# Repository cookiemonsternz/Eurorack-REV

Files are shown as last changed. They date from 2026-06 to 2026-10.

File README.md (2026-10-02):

# REV
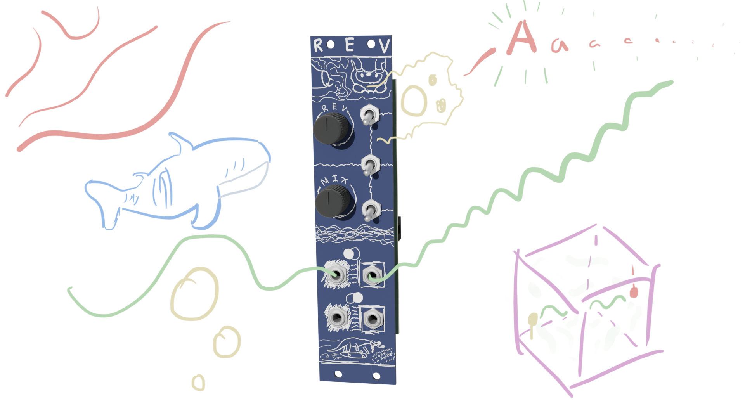
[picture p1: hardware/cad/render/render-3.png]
Render 3

_Digital reverb / delay eurorack module, user programmable and customisable._

#### What?
The next effect in a series of eurorack modules! REV is a custom digital reverb/delay processer, utilising the rp2040 mcu. Includes firmware for a basic algorithmic reverb, completely configurable via software. Default configuration uses 60kb of sram out of 264kb max. 

In terms of controls, REV features two potentiometers and 3 switches, which are by default configured to control reverb length and mix, with the switches adjusting brightness, density and stereo mixing.

#### Why?
Reverb is a very widely used effect, and arguably one of the most important in synthesizers. It sounds pretty cool but is unfortunately quite tricky to do completely analog. This module aims to provide a convenient and open source base to not only use as a reverb module, but also to prototype other digital effects.

I personally decided to make it due to my frustration with constantly having to lug around my laptop whenever I wanted reverb on my synth (which doesn't have an in-built fx section). A eurorack module is much more convenient. Having it be my own hardware allows for much more customisation than off the shelf modules / pedals, which I find very attractive.

#### How to use?
REV is a stereo board, it has an input and output for left and right, and the controls are all labelled.

In terms of getting it set up, you'll need to program the rp2040. To do this, bridge J4, which will allow you to program the flash, and then plug in the usb port. The rp2040 should show up as USB Mass Storage Device. Copy the uf2 file from the releases tab folder into the device and then disconnect J4 and unplug the usb. When you power it up via the eurorack power connector (not usb) the module should be functional.

## Renders
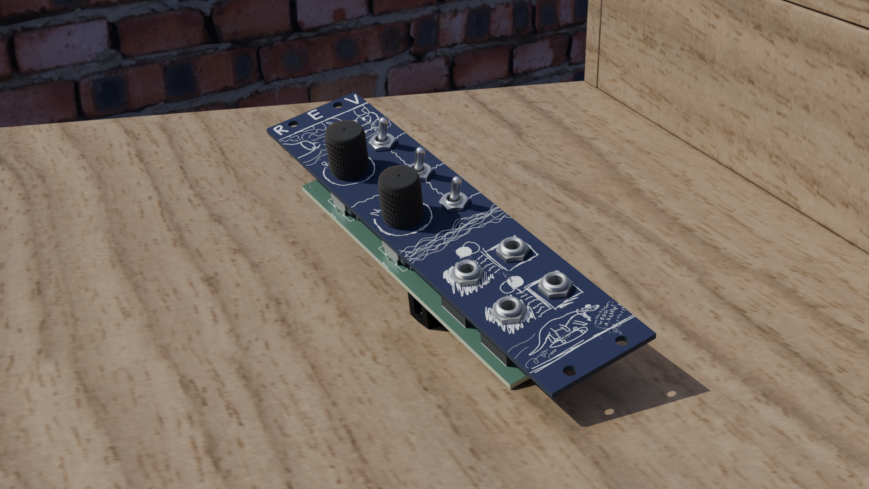
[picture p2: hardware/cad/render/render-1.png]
Render 1

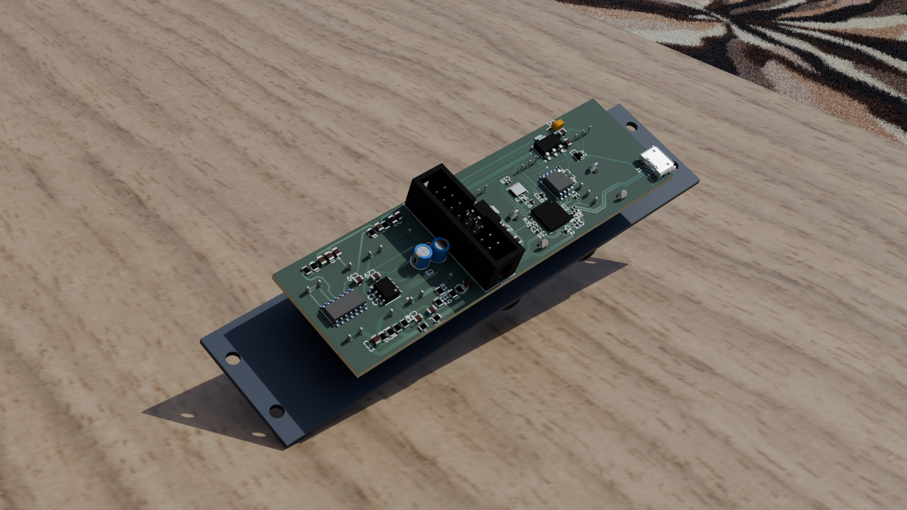
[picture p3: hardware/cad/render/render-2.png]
Render 2

Board front
Board back
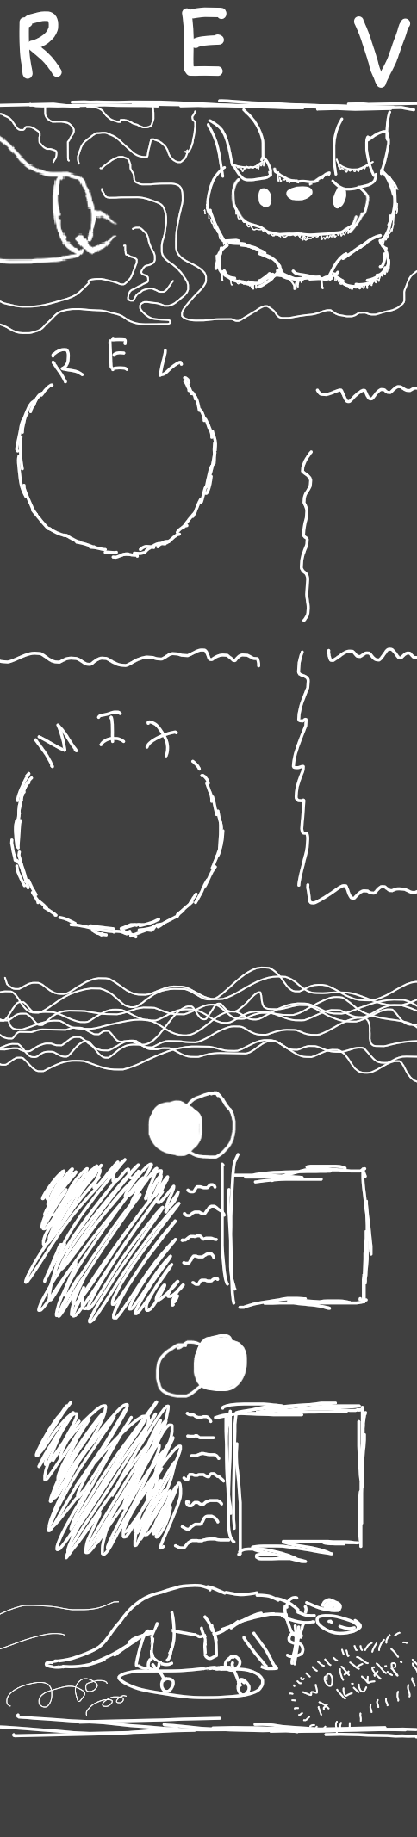
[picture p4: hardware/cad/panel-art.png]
Panel art


## Schematics
Schematic
PCB Front
PCB Back

## Zine Page
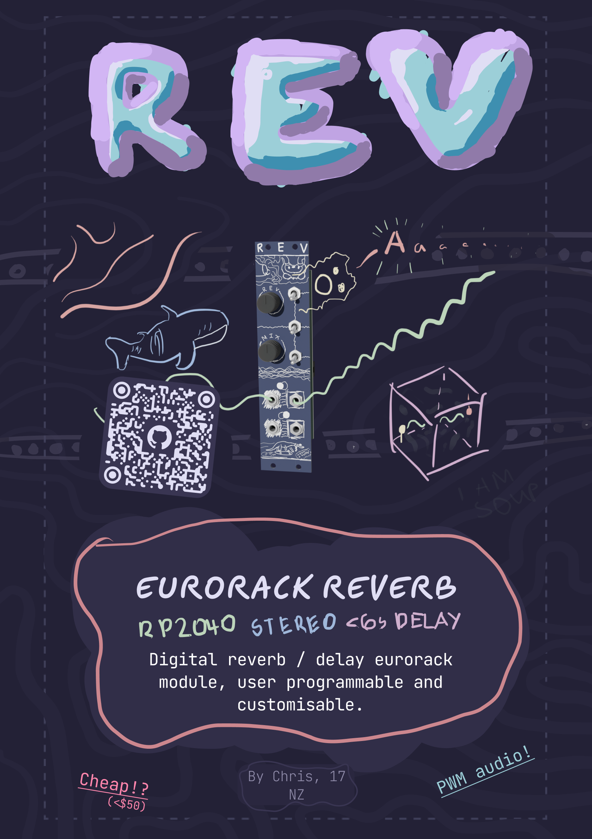
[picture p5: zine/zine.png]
Zine page


## BOM
_Needed is how many I personally need :)_
| Part | Quantity | Needed | Source | Link | Lot / Min Amount | Unit | Net | Running |
|---|---|---|---|---|---|---|---|---|
| **Capacitors** | | | | | | | | |
| 100n Cap, 0805 | 19 | 19 | JLCPCB | https://jlcpcb.com/partdetail/YAGEO-CC0805KRX7R9BB104/C49678 | 1 | $0.0094 | $0.1786 | $0.18 |
| 1u Cap, 0805 | 2 | 2 | JLCPCB | https://jlcpcb.com/partdetail/29074-CL21B105KBFNNNE/C28323 | 1 | $0.0190 | $0.0380 | $0.22 |
| 10u Cap, 0805 | 4 | 4 | JLCPCB | https://jlcpcb.com/partdetail/16532-CL21A106KAYNNNE/C15850 | 1 | $0.0472 | $0.1888 | $0.41 |
| 47u Cap, 0805 | 2 | 2 | JLCPCB | https://jlcpcb.com/partdetail/17464-CL21A476MQYNNNE/C16780 | 1 | $0.0921 | $0.1842 | $0.59 |
| 10u Electrolytic Cap, D4.0xP1.5 | 2 | 0 | LCSC | https://www.lcsc.com/product-detail/C88726.html | 10 | $0.0564 | $0.5600 | $1.15 |
| 22u Tantalum Cap, CASE-A-3216-18(mm) | 2 | 2 | LCSC | https://www.lcsc.com/product-detail/C11366.html | 1 | $0.2379 | $0.4758 | $1.63 |
| **Resistors** | | | | | | | | |
| 22? Resistor, 0805 | 2 | 2 | JLCPCB | https://jlcpcb.com/partdetail/18249-0805W8F220JT5E/C17561 | 1 | $0.0027 | $0.0054 | $1.63 |
| 100? Resistor, 0805 | 2 | 2 | JLCPCB | https://jlcpcb.com/partdetail/18096-0805W8F1000T5E/C17408 | 1 | $0.0023 | $0.0046 | $1.64 |
| 220? Resistor, 0805 | 2 | 2 | JLCPCB | https://jlcpcb.com/partdetail/18245-0805W8F2200T5E/C17557 | 1 | $0.0031 | $0.0062 | $1.64 |
| 3.9k? Resistor, 0805 | 2 | 2 | JLCPCB | https://jlcpcb.com/partdetail/18302-0805W8F3901T5E/C17614 | 1 | $0.0031 | $0.0062 | $1.65 |
| 10k? Resistor, 0805 | 5 | 5 | JLCPCB | https://jlcpcb.com/partdetail/18102-0805W8F1002T5E/C17414 | 1 | $0.0029 | $0.0145 | $1.66 |
| 1M? Resistor, 0805 | 2 | 2 | JLCPCB | https://jlcpcb.com/partdetail/18202-0805W8F1004T5E/C17514 | 1 | $0.0024 | $0.0048 | $1.67 |
| **Other** | | | | | | | | |
| Schottky Diode, SOD-323 | 2 | 2 | JLCPCB | https://jlcpcb.com/partdetail/GuangdongHottech-1N5819WS/C191023 | 1 | $0.0111 | $0.0222 | $1.69 |
| PJ301M-12 Jacks | 4 | 0 | Aliexpress | www.aliexpress.com/item/1005004864182675.html | 10 | $4.4000 | $0.0000 | $1.69 |
| RK09K 100k Potentiometer | 2 | 0 | Aliexpress | https://www.aliexpress.com/item/1005007278123055.html | 5 | $1.0400 | $0.0000 | $1.69 |
| TL072CDT | 1 | 1 | JLCPCB | https://jlcpcb.com/partdetail/STMicroelectronics-TL072CDT/C6961 | 1 | $0.1568 | $0.1568 | $1.85 |
| X322512MSB4SI 12MHz Crystal | 1 | 1 | JLCPCB | https://jlcpcb.com/partdetail/YXC_CrystalOscillators-X322512MSB4SI/C9002  | 1 | $0.0740 | $0.0740 | $1.92 |
| 74HC04D Logic Inverter | 1 | 1 | JLCPCB | https://jlcpcb.com/partdetail/Nexperia-74HC04D653/C5590 | 1 | $0.1521 | $0.1521 | $2.07 |
| W25Q128JVS Flash | 1 | 1 | JLCPCB | https://jlcpcb.com/partdetail/WinbondElec-W25Q128JVSIQ/C97521 | 1 | $2.6146 | $2.6146 | $4.69 |
| AMS1117-3.3 LDO | 2 | 2 | JLCPCB | https://jlcpcb.com/partdetail/Advanced_MonolithicSystems-AMS1117_33/C6186 | 1 | $0.2024 | $0.4048 | $5.09 |
| RP2040 MCU | 1 | 1 | JLCPCB | https://jlcpcb.com/partdetail/RaspberryPi-RP2040/C2040 | 1 | $0.9843 | $0.9843 | $6.08 |
| IDC Connector | 1 | 0 | LCSC | https://www.lcsc.com/product-detail/C7430313.html | 5 | $0.0834 | $0.0000 | $6.08 |
| USB B Micro Port | 1 | 1 | JLCPCB | https://jlcpcb.com/partdetail/SHOUHAN-MicroXNJ/C404969 | 1 | $0.0406 | $0.0406 | $6.12 |
| SPDT Switch | 3 | 0 | Aliexpress | https://www.aliexpress.com/item/1005005370002265.html | 5 | $0.8520 | $0.0000 | $6.12 |
| **Non-Components** | | | | | | | | |
| Aluminium Plate (100x200x2mm) | 1 | 1 | Aliexpress | https://www.aliexpress.com/item/1005007160296738.html | 1 | $6.2300 | $6.2300 | $12.35  |
| PCB | 1 | 1 | JLCPCB | NA | 5 | $0.8200 | $4.1000 | $16.45  |
| **Total** | | | | | | | | $16.45  |

| Totals | Money  |
|---|---|
| Aliexpress, Inc. Shipping + Tax | $7.35  |
| JLCPCB, Inc. Shipping + Tax | $41.21 |
| **Total** | $48.56 |

## CAD Links
Heres the links to the CAD source, Onshape:
[Panel source](https://cad.onshape.com/documents/1214f87d69295045284472ae/w/920e2a43c1f3f44d8378acda/e/9f1143cafdcad0010397ac9a)

## Directory Structure
- **hardware/**
    - **bom/** - BOM Files (CSV and LibreOffice Calc)
    - **cad/** - CAD Files
        - **render/** - Files for rendering (inc. gltf models)
    - **rev/** - KiCad files
        - **lib/** - External libraries
        - **production/** - Production files (Gerber, etc.)
        - **plots/** - Schematic plot
- **journals/**
- **zine/** - Zine page

## References
[RP2040 Hardware Guide](https://pip-assets.raspberrypi.com/categories/814-rp2040/documents/RP-008279-DS-1-hardware-design-with-rp2040.pdf)

#### This project was created for [Hack Club](https://hackclub.com/) - [Fallout](https://fallout.hackclub.com/)

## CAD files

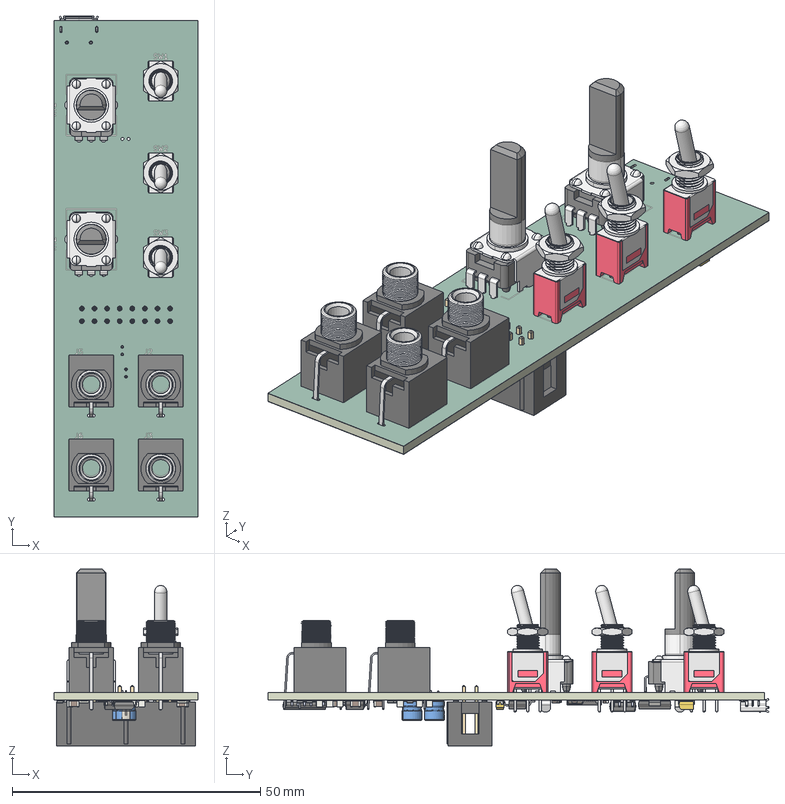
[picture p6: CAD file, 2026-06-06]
hardware/cad/board.step
29.0 x 101.0 x 35.6 mm
200-MSP-1-T3-B1-M2-PE-rev2 x 3
RK09K1130BGM x 2
D_SOD-323 x 2
C_0805_2012Metric x 16
R_0805_2012Metric x 14
C_0402_1005Metric x 13
CP_EIA-3216-18_Kemet-A x 2
IDC-Header_2x08_P2.54mm_Vertical
R_0402_1005Metric x 4
CP_Radial_D4.0mm_P1.50mm x 2
Crystal_SMD_3225-4Pin_3.2x2.5mm
SOT-223 x 2
QFN-56-1EP_7x7mm_P0.4mm_EP3.2x3.2mm
MICROXNJ
W25Q128JVSIQ
74HC04D
SOIC-8_3.9x4.9mm_P1.27mm
rev_silkscreen x 2
rev_soldermask x 2
rev_PCB

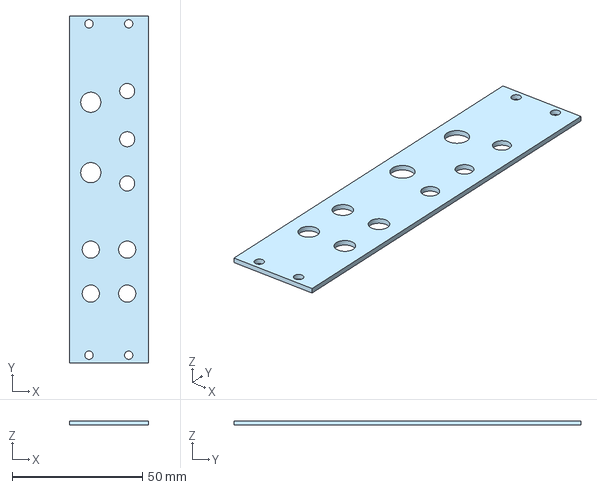
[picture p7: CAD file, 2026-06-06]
hardware/cad/Panel.step
30.2 x 133.3 x 1.59 mm

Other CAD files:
hardware/cad/render/render.blend

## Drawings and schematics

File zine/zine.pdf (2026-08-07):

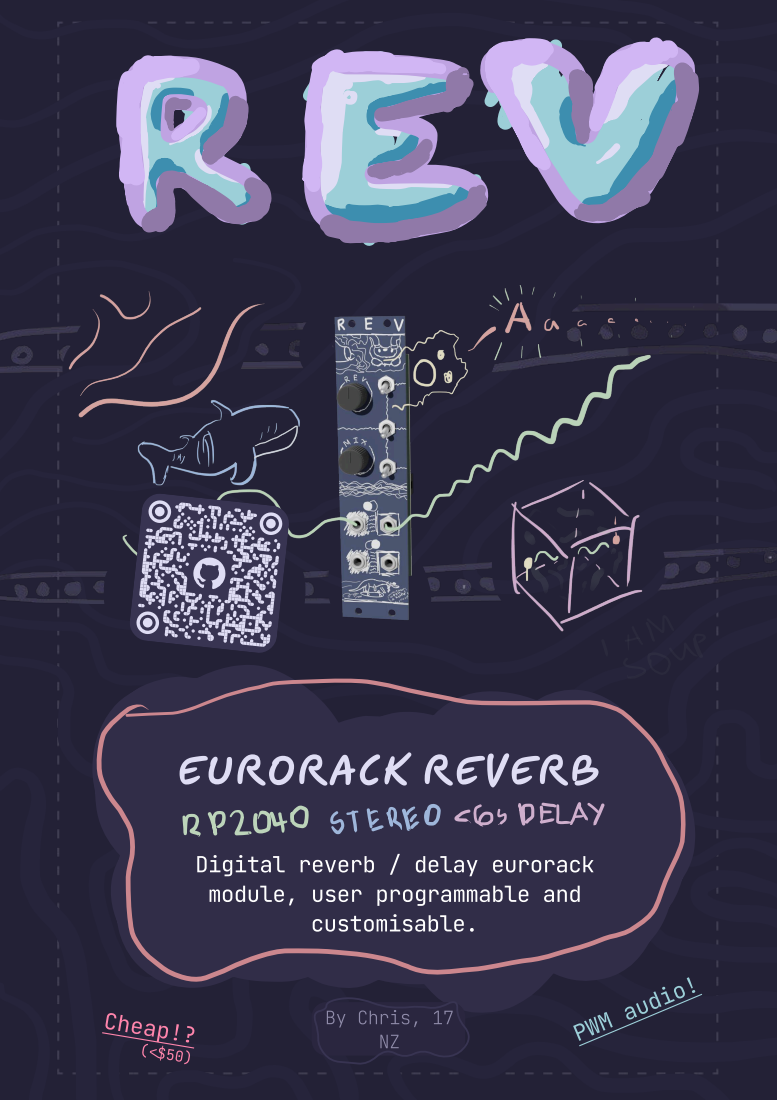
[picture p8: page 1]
EURORACK REVERB; customisable.; PWM audio!; By Chris, 17 NZ; Cheap!?

Digital reverb / delay eurorack
module, user programmable and

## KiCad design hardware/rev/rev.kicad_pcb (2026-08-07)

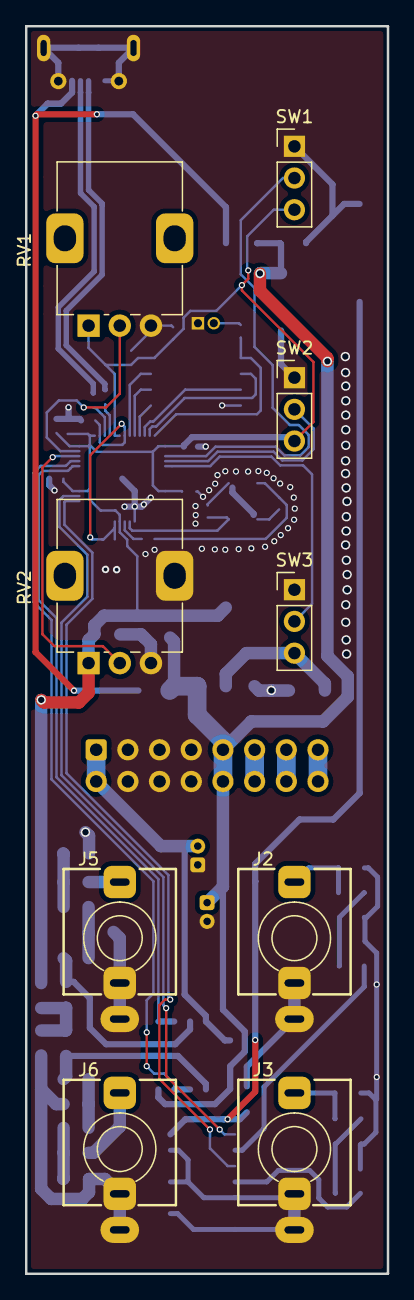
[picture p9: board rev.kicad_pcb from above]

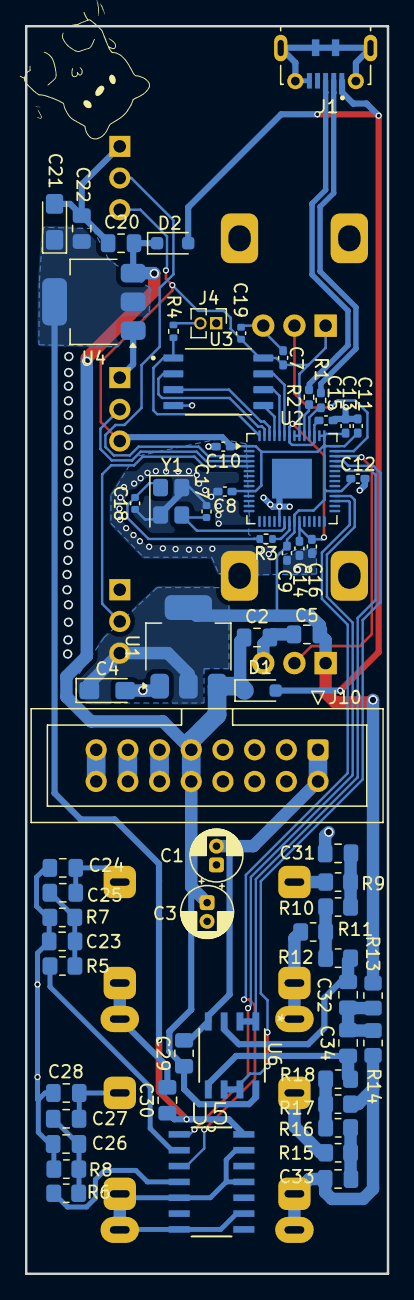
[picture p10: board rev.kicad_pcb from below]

Board: 2 copper layers, 29.0 x 100.0 mm, 72 parts (63 on the bottom side), 45 nets.

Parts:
C1, C3: 10u; CP_Radial_D4.0mm_P1.50mm
C2, C5, C20, C22: 10u; C_0805_2012Metric_Pad1.18x1.45mm_HandSolder
C4, C21: 22u; CP_EIA-3216-18_Kemet-A_HandSolder
C7, C8, C9, C10, C11, C12, C14, C15: 100n; C_0402_1005Metric_Pad0.74x0.62mm_HandSolder
C13, C16: 1u; C_0402_1005Metric_Pad0.74x0.62mm_HandSolder
C17, C18: 20p; C_0402_1005Metric
C19: 100n; C_0402_1005Metric
C23, C24, C26, C28, C29, C30, C31, C32, C33, C34: 100n; C_0805_2012Metric_Pad1.18x1.45mm_HandSolder
C25, C27: 47u; C_0805_2012Metric_Pad1.18x1.45mm_HandSolder
D1, D2: D_Schottky; D_SOD-323_HandSoldering
J1: USB_B_Micro; SHOUHAN_MICROXNJ
J2: OUT_L; Jack_3.5mm_QingPu_WQP-PJ301M-12_Vertical
J3: OUT_R; Jack_3.5mm_QingPu_WQP-PJ301M-12_Vertical
J4: Conn_01x02; PinHeader_1x02_P1.27mm_Vertical
J5: IN_L; Jack_3.5mm_QingPu_WQP-PJ301M-12_Vertical
J6: IN_R; Jack_3.5mm_QingPu_WQP-PJ301M-12_Vertical
J10: Conn_02x08_Odd_Even; IDC-Header_2x08_P2.54mm_Vertical
R1, R2: 22; R_0402_1005Metric_Pad0.72x0.64mm_HandSolder
R3, R4: 1k; R_0402_1005Metric
R5, R6: 220; R_0805_2012Metric_Pad1.20x1.40mm_HandSolder
R7, R8: 100; R_0805_2012Metric_Pad1.20x1.40mm_HandSolder
R9, R12, R15, R18: 1M; R_0805_2012Metric_Pad1.20x1.40mm_HandSolder
R10, R13, R14, R16: 10k; R_0805_2012Metric_Pad1.20x1.40mm_HandSolder
R11, R17: 3.9k; R_0805_2012Metric_Pad1.20x1.40mm_HandSolder
RV1, RV2: 100k; Potentiometer_Alps_RK09K_Single_Vertical
SW1, SW2, SW3: SW_SPDT; PinHeader_1x03_P2.54mm_Vertical
U1, U4: AMS1117-3.3; SOT-223-3_TabPin2
U2: RP2040; QFN-56-1EP_7x7mm_P0.4mm_EP3.2x3.2mm
U3: W25Q128JVS; SOIC127P790X216-8N
U5: 74HC04; SOIC127P600X175-14N
U6: TL072; D8_TEX_STM
Y1: YSX321SL 12MHz Crystal; Crystal_SMD_3225-4Pin_3.2x2.5mm

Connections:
+3.3V: C4.1, C5.1, C7.1, C8.1, C9.1, C10.1, C11.1, C12.1, C13.2, C19.1, R13.1, RV1.1, RV2.1, SW1.3 (C), SW2.3 (C), SW3.3 (C), U1.2 (VO), U2.1 (IOVDD), U2.10 (IOVDD), U2.22 (IOVDD), U2.33 (IOVDD), U2.42 (IOVDD), U2.43 (ADC_AVDD), U2.44 (VREG_VIN), U2.48 (USB_VDD), U2.49 (IOVDD), U3.8 (VCC)
+12V: C2.1, C3.1, C20.1, C29.1, D1.1 (K), D2.1 (K), J10.9, J10.10, U1.3 (VI), U4.3 (VI), U6.8 (V+)
-12V: C1.2, C29.2, J10.1, J10.2, U6.4 (V-)
/Net_USB_D+: R2.2, U2.47 (USB_DP)
/Net_USB_D-: R1.2, U2.46 (USB_DM)
/PWM_L: C24.1, C25.2, J2.T
/PWM_R: C27.2, C28.1, J3.T
AUDIO_3.3V: C21.1, C22.1, C30.1, U4.2 (VO), U5.14 (VCC)
BIAS: C32.2, C34.2, R13.2, R14.1
GND: C1.1, C2.2, C3.2, C4.2, C5.2, C7.2, C8.2, C9.2, C10.2, C11.2, C12.2, C13.1, C14.1, C15.1, C16.2, C17.2, C18.1, C19.2, C20.2, C21.2, C22.2, C23.2, C24.2, C26.2, C28.2, C30.2, C31.2, C33.2, J1.5 (GND), J1.SH (Shield), J2.S, J2.TN, J3.S, J3.TN, J4.1, J5.S, J5.TN, J6.S, J6.TN, J10.3, J10.4, J10.5, J10.6, J10.7, J10.8, R7.2, R8.2, R11.1, R14.2, R17.1, RV1.3, RV2.3, RV2.MP, SW1.1 (A), SW2.1 (A), SW3.1 (A), U1.1 (GND), U2.19 (TESTEN), U2.57 (GND), U3.4 (GND), U4.1 (GND), U5.5, U5.7 (GND), U5.9, U5.11, U5.13, Y1.2 (G), Y1.4 (G)
IN_L: U2.38 (GPIO26/ADC0), U6.1, U6.2 (-)
IN_R: U2.39 (GPIO27/ADC1), U6.6 (-), U6.7
unnamed: C18.2, R3.2, Y1.1
unnamed: C23.1, C25.1, R5.2, R7.1
unnamed: C26.1, C27.1, R6.2, R8.1
unnamed: C31.1, R9.2, R10.1
unnamed: C33.1, R15.2, R16.1
unnamed: J4.2, R4.1
unnamed: J5.T, R9.1
unnamed: J6.T, R15.1
unnamed: R5.1, U5.2
unnamed: R6.1, U5.4
unnamed: R10.2, R11.2, R12.1
unnamed: R16.2, R17.2, R18.1
unnamed: C14.2, C15.2, C16.1, U2.23 (DVDD), U2.45 (VREG_VOUT), U2.50 (DVDD)
unnamed: C32.1, R12.2, U6.3 (+)
unnamed: C34.1, R18.2, U6.5 (+)
OUT_L: U2.32 (GPIO21), U5.1
OUT_R: U2.31 (GPIO20), U5.3
POT_1: RV1.2, U2.41 (GPIO29/ADC3)
POT_2: RV2.2, U2.40 (GPIO28/ADC2)
QSPI_SCLK: U2.52 (QSPI_SCLK), U3.6 (CLK)
QSPI_SD0: U2.53 (QSPI_SD0), U3.5 (DI(IO0))
QSPI_SD1: U2.55 (QSPI_SD1), U3.2 (DO(IO1))
QSPI_SD2: U2.54 (QSPI_SD2), U3.3 (IO2)
QSPI_SD3: U2.51 (QSPI_SD3), U3.7 (IO3)
QSPI_SS: R4.2, U2.56 (~QSPI_SS), U3.1 (~CS)
SW_1: SW1.2 (B), U2.3 (GPIO1)
SW_2: SW2.2 (B), U2.4 (GPIO2)
SW_3: SW3.2 (B), U2.5 (GPIO3)
USB_D+: J1.3 (D+), R2.1
USB_D-: J1.2 (D-), R1.1
VBUS: D1.2 (A), D2.2 (A), J1.1 (VBUS)
XIN: C17.1, U2.20 (XIN), Y1.3
XOUT: R3.1, U2.21 (XOUT)

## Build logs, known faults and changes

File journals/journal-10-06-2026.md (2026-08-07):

# REV Journal 3 - 10/06/2026

Welp been a few days, I started work on another project but I'm getting back to work on this one today. 

Heres the checklist from last time again:
- [x] Panel Art
- [ ] Finished BOM
- [x] Renders
- [ ] Readme
- [ ] Zine page

---

First up on my list for today: Finishing up the bom.
Heres the main bom
BOM

Just need to add the totals, but before that I did a bit of work on the pcb. I went through and fixed all the drc errors (all pretty basic stuff) and then tidied up the bottom silkscreen.
Bottom Silkscreen

And then going through and doing some totals:
Totals

PCBA is quite expensive :( can't solder the stuff by hand though (don't have a hot plate) so not many options really. I saw something about a coupon on slack so I might try and get that. 

- [x] Panel Art
- [x] Finished BOM
- [x] Renders
- [ ] Readme
- [ ] Zine page
- [ ] Firmware

Next up, the readme :) Yet again just going to copy and adapt it from the other projects, should be pretty chill. This one has firmware so I'll add some flashing instructions as well (might write that section after I've actually got some firmware, could provide a wee guide on how to make some).

---

Readme is done :) Not really any screenshots but you can go and look at the readme and see what it is lol. 
Still to do:
- [x] Panel Art
- [x] Finished BOM
- [x] Renders
- [x] Readme
- [ ] Render 3 (For zine and readme)
- [ ] Zine page
- [ ] Firmware

I'm going to do a bit of work on the firmware now. Gonna use the C/C++ SDK for once instead of micropython or anything.

Nevermind I guess I'm not doing that right now, school wifi is abhorrent and I can't install the stuff required. I'll wait till I get home :)

---

Setting up the final render instead:
Final render setup
I can't do the grease pencil till I'm home, because I don't have my drawing tablet on me and I need the variable width lol.

I'll chuck this into stuff as a placeholder though.

---

I can get started on some of the zine, again not all of it lol, but yknow.

---

SIKE! I ended up just not doing anything for the rest of the day lol. Its now the next day (I would say morning but I've already done all the work and I'm writing this at like midnight) and I've spent most of the day writing the firmware. I'm happy to say that it is done!

It took a bunch of stiching together of a bunch of sources and a lot of reading docs but it is done :) 
Heres a general overview of what goes on:

Every loop, we:
Wait for data to transfer from the adc via dma
Copy the data into a working buffer, scaling to the correct range
Read the control inputs and update values accordingly
Restart the dma capture
Process the working buffer
Copy the working buffer to the output, writing via pwm (this step is iffy and I'd really like to test it in person lol)

I stole a bunch of the reverb algorithm and code from [an open source implementation on github](https://github.com/SergeiGorskiy/IFMO_Reverb/tree/master/Freeverb_original), but it was spread out as a bunch of cpp, so I had to flatten it and rewrite everything to just use a bunch of big buffers. Speaking of, it should only use ~65kB of memory for the main allpass and comb buffers, and the rp2040 has 256kB of ram. Pretty comfortable margin which might mean I'm able to overclock past 48kHz.

Man i totally forgot how much i enjoyed coding firmware, been a hot minute lol :)

Anyways, I'm gonna wrap it up here for the night. This project is very very close to done now, only the last admin-y bits to polish off and then its good to go :)
Gn <3

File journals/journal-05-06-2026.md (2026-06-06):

# REV Journal 2 - 05/06/2026

Starting off today, and I reckon I should probably add some knobs :) 
Kinda completely forgot i should have inputs for it, anyways, I settled on two knobs (for the two free adc channels I have left) and 3 switches, which I'll program to do stuff later.

Controls

---

Annd after a wee bit of work, the bom and footprint assignment is done-ish:
BOM

And bringing it into the pcb:
PCB Pre-layout

Yeah I reckon I'll be able to squeeze this one pretty tight :)
PCB basic layout
I reckon that this will be a decent enough layout, so I'll get some proper measurements in.
I'm going to go for a 6HP unit, which is ~30.5mm wide, and as always 133.35mm, giving me a board size of 29mmx100mm.

And heres the final overarching layout:
Full layout

Next up, laying out all the components:

---

Getting to about halfway through and I've decided to swap to 0402 components for the rp2040 filter caps, just makes it a lot easier to squeeze everything, the 0805 caps are like a quarter of the size of the actual mcu lol.
- [ ] TODO Update bom for C6-C16 to 0402
- [ ] TODO Update bom for R1,R2 to 0402

And now its fully layed out and routed :)
Back
Front

And in 3d:
Back 3d

Looking pretty good :). I tried to optimise the MCU section decently well, fencing off the crystal and all that crap, not sure if it'll help much but whatevs. 

Gonna call the pcb done for now, and move onto the plate and stuff :O

Heres the panel:
Panel Sketch
And in 3d:
3d

And thats pretty much the main part of the project done!
Heres my checklist of things still to go:
- [ ] Panel Art
- [ ] Finished BOM
- [ ] Renders
- [ ] Readme
- [ ] Zine page

Not too much at all :)
I'll get the first bit of the render set up tonight, and maybe the panel art / README.

---

Spent a bit of time on the panel art, and came up with this, which I'm reasonably happy with:
Panel art
Might be a teensy bit cluttered but I think it looks fine so who cares :)

Bringing it into blender, and heres the first render (i am seuss holy bars)

Render 1
Render 2

I am gonna call it for the day here though, I'll finish off the readme / last render and zine tomorrow :)

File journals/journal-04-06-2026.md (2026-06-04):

# REV Journal 1 - 04/06/2026

Welcome back! New project time, this time a delay module :)

I've already done a tiny bit of research, and I've opted to go for a digital circuit this time, as if I were using a BBD (bucket-brigade device) I wouldn't really be able to simulate it and I don't trust my analogue skills enough to make the changes I'd need to make the circuit my own. 

For the digital chip, I've decided to go with the rp2040. The main reason is just because I'm exceedingly familiar with it, I've made several projects utilising it successfully already, and it also has really good documentation and support (being the main chip in the RP Pico). Its ADC should be adequate, as it has a sampling rate of 500kHz, well above the 44.1kHz requirement I'd want. For output, I could either use a DAC, or try and finagle something with pwm. The PWM approach is quite apealling, as it reduces cost, complexity, and latency, but it might result in a bit of audio quality decrease.

The main problem with PWM is you get a lot of the carrier signal in the output. If your pwm is running at ~10khz, there will be buzzing at 10kHz. A couple options for this are to chuck the pwm frequency outside of audible range, ~100kHz would probably be fine. Given the rp2040 can run at a clock speed of up to 133MHz (nvm its 200MHz actually lol), it should probably be fine to take this approach. The only downside is that this does take processing time, which I'd really like to dedicate to the actual audio processing. Overall though I think I will go with pwm audio.

I'm just going to get straight into the schematic now, and just take things as they go :)

First of all, the generic rp2040 boilerplate stuff:
RP2040 setup

And then the power section, this is a bit different to the hardware example by rpi, as I want to be able to program the chip by usb and not destroy my laptop if the board is plugged in to eurorack while programming with usb, so I just added a wee resistor. Also using a different ldo because the reccomended one isn't available as a basic part on jlcpcb.

Power section

Also just swapped out the crystal for one thats a basic part. Same frequency, just different load capacitors.

Honestly that already almost done, just need audio input and output lol. I'm going to build it with the capability for stereo, but I don't expect it to work out due to processing constraints, but the user doesnt have to know that :)

---

### Audio output

I'm pretty much just stealing the circuit from the hardware guide: 
A seperate ldo for audio, and then buffering and filtering. Instead of the suggested logic buffer, I'm using a logic inverter, as theres no buffers in the basic parts list and inverters do pretty much the same thing ;)

Output section

### Audio input

The audio input is pretty basic, first just make sure its centered around ground, then divide it down to ~2.8V p2p assuming that the input is from -5 to 5v. I went for 2.8V just in case the input goes a bit high, so that the input doesn't get fried lol.
Finally, I bias it to ~1/2 of 3.3V so that the full range of the wave can be captured by the adc, buffer it, and send it off to the mcu.

Audio input section

And thats pretty much the entire circuit done :)
Full circuit

Tomorrow: BOM, PCB and Panel 
Till then !

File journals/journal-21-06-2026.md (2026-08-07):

# REV Journal 4 - 11/06/2026

Welp.
Been a minute lol :|
buuuutt for a good reason! Life has been very busy and I've also joined as a reviewer for fallout! So thats been taking up all my time (voluntarily so i can't really complain lol, its good fun). But its midnight and I can't sleep and I'm already exhausted from reviewing today, so I figured I might as well finish this project off and get it submitted :)

Iirc, there wasn't much left to do, but i'll just compile a little list now.

- [ ] Zine
- [ ] Funky lines in render-3

Welp thats not much lol. Should be a reasonably quick time <3

I guess I'll just get straight into it! Starting with blender because that'll be quicker.

Heres what I came up with:
Render-3
Not my best-best work but its alright. If I'm really unhappy I'll fix it later but the 1 am brain is getting to me :sob:

Next up: the zine :)

---

Wee bit on and I've got it to here:
Current zine

I am going to leave it there, as my brain is absolutely addled by the time :sob:. I'm also probs a bit exhausted from yesterday still so yeah, gn <3

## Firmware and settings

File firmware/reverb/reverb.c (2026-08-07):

/**
 * Copyright (c) 2020 Raspberry Pi (Trading) Ltd.
 *
 * SPDX-License-Identifier: BSD-3-Clause
 */

//------ TODO ------//
// - Rewrite audio output to pull data using dma instead of using
// pwm interrupts - See https://github.com/earlephilhower/arduino-pico/blob/master/libraries/PWMAudio/src/PWMAudio.cpp
// in PWMAudio::begin()
// - Move algorithm to a different file
// - Bind controls
//------      ------//

#include "hardware/adc.h"
#include "hardware/dma.h"
#include "hardware/pwm.h"
#include "hardware/gpio.h"
#include "hardware/irq.h"
#include <hardware/regs/dreq.h>
#include <hardware/structs/adc.h>
#include <hardware/structs/io_bank0.h>
#include <stdbool.h>
#include <stdint.h>


//- INPUT & PROCESSING -//
#define INPUT_PIN_L 26
#define INPUT_PIN_R 27

// Sampling frequency in Hz
#define SAMPLING_FREQ 44100
// Sample transfer count, per channel
#define SAMPLES 256

int16_t sampleBuffer[SAMPLES * 2]; // DMA Buffer, interlaced L/R
int16_t streamBufferL[SAMPLES]; // Scaled working buffer, split into stereo
int16_t streamBufferR[SAMPLES]; // Scaled working buffer, split into stereo

dma_channel_config config;
int dma_chan;

//- OUTPUT -//
#define OUTPUT_PIN_L 20
#define OUTPUT_PIN_R 21

uint slice_l;
uint slice_r;
uint32_t clockdiv;

uint32_t index_l;
uint32_t index_r;

//- CONTROLS -//
#define NUM_POTS 2
const uint POT_CHANNELS[NUM_POTS] = {2, 3};
uint16_t pot_values[NUM_POTS] = {0, 0};

#define NUM_SWITCHES 3
const uint SWITCH_PINS[NUM_SWITCHES] = {1, 2, 3};
bool switch_states[NUM_SWITCHES] = {false};

//- ALGORITHM -//
#define	NUM_COMBS	8
#define	NUM_ALLPASSES 4
#define MUTED 0
#define FIXED_GAIN 0.015f
#define SCALE_WET 3.0f
#define SCALE_DRY 2.0f
#define SCALE_DAMP 0.4f
#define SCALE_ROOM 0.28f
#define OFFSET_ROOM 0.7f
#define INITIAL_ROOM 0.5f
#define INITIAL_DAMP 0.5f
#define INITIAL_WET (1.0f/SCALE_WET)
#define INITIAL_DRY	0.0f
#define INITIAL_WIDTH 1.0f
#define INITIAL_MODE 0.0f
#define FREEZE_MODE	0.5f
#define STEREO_SPREAD 23

// These values assume 44.1KHz sample rate
// they will probably be OK for 48KHz sample rate
// but would need scaling for 96KHz (or other) sample rates.
// The values were obtained by listening tests.
// Total is around 15000, assuming 4 byte float this is 60KB of memory.
#define COMB_TUNING_L1		 1116
#define COMB_TUNING_R1		 (1116+STEREO_SPREAD)
#define COMB_TUNING_L2		 1188
#define COMB_TUNING_R2		 (1188+STEREO_SPREAD)
#define COMB_TUNING_L3		 1277
#define COMB_TUNING_R3		 (1277+STEREO_SPREAD)
#define COMB_TUNING_L4		 1356
#define COMB_TUNING_R4		 (1356+STEREO_SPREAD)
#define COMB_TUNING_L5		 1422
#define COMB_TUNING_R5		 (1422+STEREO_SPREAD)
#define COMB_TUNING_L6		 1491
#define COMB_TUNING_R6		 (1491+STEREO_SPREAD)
#define COMB_TUNING_L7		 1557
#define COMB_TUNING_R7		 (1557+STEREO_SPREAD)
#define COMB_TUNING_L8		 1617
#define COMB_TUNING_R8		 (1617+STEREO_SPREAD)
#define ALLPASS_TUNING_L1	 556
#define ALLPASS_TUNING_R1	 (556+STEREO_SPREAD)
#define ALLPASS_TUNING_L2	 441
#define ALLPASS_TUNING_R2	 (441+STEREO_SPREAD)
#define ALLPASS_TUNING_L3	 341
#define ALLPASS_TUNING_R3	 (341+STEREO_SPREAD)
#define ALLPASS_TUNING_L4	 225
#define ALLPASS_TUNING_R4	 (225+STEREO_SPREAD)

// Buffers for the combs
float	bufcombL1[COMB_TUNING_L1];
float	bufcombR1[COMB_TUNING_R1];
float	bufcombL2[COMB_TUNING_L2];
float	bufcombR2[COMB_TUNING_R2];
float	bufcombL3[COMB_TUNING_L3];
float	bufcombR3[COMB_TUNING_R3];
float	bufcombL4[COMB_TUNING_L4];
float	bufcombR4[COMB_TUNING_R4];
float	bufcombL5[COMB_TUNING_L5];
float	bufcombR5[COMB_TUNING_R5];
float	bufcombL6[COMB_TUNING_L6];
float	bufcombR6[COMB_TUNING_R6];
float	bufcombL7[COMB_TUNING_L7];
float	bufcombR7[COMB_TUNING_R7];
float	bufcombL8[COMB_TUNING_L8];
float	bufcombR8[COMB_TUNING_R8];

// Buffers for the allpasses
float	bufallpassL1[ALLPASS_TUNING_L1];
float	bufallpassR1[ALLPASS_TUNING_R1];
float	bufallpassL2[ALLPASS_TUNING_L2];
float	bufallpassR2[ALLPASS_TUNING_R2];
float	bufallpassL3[ALLPASS_TUNING_L3];
float	bufallpassR3[ALLPASS_TUNING_R3];
float	bufallpassL4[ALLPASS_TUNING_L4];
float	bufallpassR4[ALLPASS_TUNING_R4];

// COMB BUFFERS
float* l_comb_buffers[NUM_COMBS] = { 
  bufcombL1,
  bufcombL2,
  bufcombL3,
  bufcombL4,
  bufcombL5,
  bufcombL6,
  bufcombL7,
  bufcombL8 
};
const int L_COMB_BUFFER_LENGTHS[NUM_COMBS] = {
  COMB_TUNING_L1,
  COMB_TUNING_L2,
  COMB_TUNING_L3,
  COMB_TUNING_L4,
  COMB_TUNING_L5, 
  COMB_TUNING_L6,
  COMB_TUNING_L7,
  COMB_TUNING_L8
}; 
float* r_comb_buffers[NUM_COMBS] = { 
  bufcombR1,
  bufcombR2,
  bufcombR3,
  bufcombR4,
  bufcombR5,
  bufcombR6,
  bufcombR7,
  bufcombR8 
};
const int R_COMB_BUFFER_LENGTHS[NUM_COMBS] = {
  COMB_TUNING_R1,
  COMB_TUNING_R2,
  COMB_TUNING_R3,
  COMB_TUNING_R4,
  COMB_TUNING_R5, 
  COMB_TUNING_R6,
  COMB_TUNING_R7,
  COMB_TUNING_R8
}; 
// ALLPASS BUFFERS
float* l_allpass_buffers[NUM_COMBS] = {
  bufallpassL1,
  bufallpassL2,
  bufallpassL3,
  bufallpassL4,
};
const int L_ALLPASS_BUFFER_LENGTHS[NUM_ALLPASSES] = {
  ALLPASS_TUNING_L1,
  ALLPASS_TUNING_L2,
  ALLPASS_TUNING_L3,
  ALLPASS_TUNING_L4,
};
float* r_allpass_buffers[NUM_COMBS] = {
  bufallpassR1,
  bufallpassR2,
  bufallpassR3,
  bufallpassR4,
};
const int R_ALLPASS_BUFFER_LENGTHS[NUM_ALLPASSES] = {
  ALLPASS_TUNING_R1,
  ALLPASS_TUNING_R2,
  ALLPASS_TUNING_R3,
  ALLPASS_TUNING_R4,
};

// Params
float comb_feedback_l[NUM_COMBS];
float comb_feedback_r[NUM_COMBS];
float comb_damp_l[NUM_COMBS];
float comb_damp_r[NUM_COMBS];
float comb_filter_store_l[NUM_COMBS];
float comb_filter_store_r[NUM_COMBS];
int comb_buf_idx_l[NUM_COMBS];
int comb_buf_idx_r[NUM_COMBS];

float allpass_feedback_l[NUM_ALLPASSES];
float allpass_feedback_r[NUM_ALLPASSES];
int allpass_buf_idx_l[NUM_ALLPASSES];
int allpass_buf_idx_r[NUM_ALLPASSES];

// Vars
float gain;
float roomsize, roomsize1;
float damp, damp1;
float wet, wet1, wet2;
float dry;
float width;
float mode;

//------ AUDIO INPUT ------//

void init_adc_dma() {
  // INIT ADC
  adc_init();

  adc_gpio_init(INPUT_PIN_L);
  adc_gpio_init(INPUT_PIN_R);

  adc_set_round_robin(0b1100); // Enable first two adc channels (L/R)

  adc_fifo_setup( //
      true,       // Write each completed conversion to sample FIFO
      true,       // Enable dma request (DREQ)
      1,          // Send DREQ when 1 sample present
      false,      // No err flag
      false       // Shift to be 1 byte in size
  );

  adc_set_clkdiv((48000000 / (SAMPLING_FREQ * 2)) - 1);

  // INIT DMA
  dma_chan = dma_claim_unused_channel(true);
  config = dma_channel_get_default_config(dma_chan);

  // Read from first add, write to incrementing.
  channel_config_set_transfer_data_size(&config, DMA_SIZE_16);
  channel_config_set_read_increment(&config, false);
  channel_config_set_write_increment(&config, true);

  channel_config_set_dreq(&config, DREQ_ADC);

  dma_channel_configure(
    dma_chan,
    &config, 
    (uint16_t *)sampleBuffer,
    &adc_hw->fifo, 
    SAMPLES, 
    true
  );

  adc_run(true);
}

//------ PWM OUTPUT ------//

void pwm_int_handler_l() {
  pwm_clear_irq(slice_l);
  if (index_l < SAMPLES) {
    pwm_set_gpio_level(OUTPUT_PIN_L, streamBufferL[index_l]);
    index_l++;
  } else {
    index_l = 0;
  }
}


void pwm_int_handler_r() {
  pwm_clear_irq(slice_r);
  if (index_r < SAMPLES) {
    pwm_set_gpio_level(OUTPUT_PIN_R, streamBufferR[index_r]);
    index_r++;
  } else {
    index_r = 0;
  }
}

void init_pwm() {
  gpio_set_function(OUTPUT_PIN_L, GPIO_FUNC_PWM);
  gpio_set_function(OUTPUT_PIN_R, GPIO_FUNC_PWM);

  slice_l = pwm_gpio_to_slice_num(OUTPUT_PIN_L);
  slice_r = pwm_gpio_to_slice_num(OUTPUT_PIN_R);

  pwm_clear_irq(slice_l);
  pwm_clear_irq(slice_r);
  pwm_set_irq_enabled(slice_l, true);
  pwm_set_irq_enabled(slice_r, true);

  irq_set_exclusive_handler(slice_l, pwm_int_handler_l);
  irq_set_exclusive_handler(slice_r, pwm_int_handler_r);

  irq_set_enabled(slice_l, true);
  irq_set_enabled(slice_r, true);

  // PWM Config
  pwm_config pwm_conf = pwm_get_default_config();

  // Base clock is 125MHz, divide by wrap, then clockdiv divides further (integer increments)
  // We want same pwm freq as sample rate, so need to get a good clockdiv and then optimise wrap from there.
  #define TOP_MAX 65534
  #define DIV_MIN ((0x01 << 4) + 0x0)
  #define DIV_MAX ((0xFF << 4) + 0xF)
  uint32_t clock = 125000000;
  clockdiv = (clock << 4) / SAMPLING_FREQ / (TOP_MAX + 1);
  if (clockdiv < DIV_MIN) {
    clockdiv = DIV_MIN;
  }
  uint32_t top = ((clock << 4) / clockdiv / SAMPLING_FREQ) - 1;

  pwm_config_set_clkdiv(&pwm_conf, clockdiv);
  pwm_config_set_wrap(&pwm_conf, top);

  pwm_init(slice_l, &pwm_conf, true);
  pwm_init(slice_r, &pwm_conf, true);

  pwm_set_gpio_level(OUTPUT_PIN_L, 0);
  pwm_set_gpio_level(OUTPUT_PIN_R, 0);
}

//------ CONTROLS ------//

void init_controls() {
  // POTS
  for (int i = 0; i < NUM_POTS; i++) {
    uint pin = POT_CHANNELS[i] + 26;

    adc_gpio_init(pin);
  }

  // SWITCHES
  for (int i = 0; i < NUM_SWITCHES; i++) {
    gpio_init(SWITCH_PINS[i]);
    gpio_set_dir(SWITCH_PINS[i], false);
  }

}

void read_controls() {
  // POTS
  for (int i = 0; i < NUM_POTS; i++) {
    uint channel = POT_CHANNELS[i];
    adc_select_input(channel);
    const float conversion_factor = 3.3f / (1 << 12);
    uint16_t result = adc_read();
    pot_values[i] = result * conversion_factor;    
  }

  // SWITCHES
  for (int i = 0; i < NUM_SWITCHES; i++) {
    uint pin = SWITCH_PINS[i];
    bool result = gpio_get(pin);
    // Not really debouncing needed
    switch_states[i] = result;
  }
}

//------ COMPUTE ------//
void update_compute_internal();

//- GET / SET -//

void set_roomsize(float value) {
  roomsize = (value * SCALE_ROOM) + OFFSET_ROOM;
  update_compute_internal();
}

float get_roomsize() {
  return (roomsize - OFFSET_ROOM) / SCALE_ROOM;
}

void set_damp(float value) {
  damp = value * SCALE_DAMP;
  update_compute_internal();
}

float get_damp() {
  return damp / SCALE_DAMP;
}

void set_wet(float value) {
  wet = value * SCALE_WET;
  update_compute_internal();
}

float get_wet() {
  return wet / SCALE_WET;
}

void set_dry(float value) {
  dry = value * SCALE_DRY;
}

float get_dry() {
  return dry / SCALE_DRY;
}

void set_width(float value) {
  width = value;
  update_compute_internal();
}

float get_width() {
  return width;
}

void set_mode(float value) {
  mode = value;
  update_compute_internal();
}

float get_mode() {
  if (mode >= FREEZE_MODE) {
    return 1;
  } else {
    return 0;
  }
}

//- COMPUTE MAIN -//
void mute() {
  if (get_mode() >= FREEZE_MODE) {
    return;
  }

  // Empty buffers
  for (int i = 0; i < NUM_COMBS; i++) {
    float* bufferL = l_comb_buffers[i];
    for (int j = 0; j < L_COMB_BUFFER_LENGTHS[i]; j++) {
      bufferL[j] = 0;
    }
    
    float* bufferR = r_comb_buffers[i];
    for (int j = 0; j < R_COMB_BUFFER_LENGTHS[i]; j++) {
      bufferR[j] = 0;
    }
  }

  for (int i = 0; i < NUM_ALLPASSES; i++) {
    float* bufferL = l_allpass_buffers[i];
    for (int j = 0; j < L_ALLPASS_BUFFER_LENGTHS[i]; j++) {
      bufferL[j] = 0;
    }
    
    float* bufferR = r_allpass_buffers[i];
    for (int j = 0; j < R_ALLPASS_BUFFER_LENGTHS[i]; j++) {
      bufferR[j] = 0;
    }
  }
}

void init_compute() {
  for (int i = 0; i < NUM_ALLPASSES; i++) {
    allpass_feedback_l[i] = 0.5f;
    allpass_feedback_r[i] = 0.5f;
  } 
  
  set_wet(INITIAL_WET);
  set_roomsize(INITIAL_ROOM);
  set_dry(INITIAL_DRY);
  set_damp(INITIAL_DAMP);
  set_width(INITIAL_WIDTH);
  set_mode(INITIAL_MODE);

  mute();
}

#define undenormalise(sample) if(((*(unsigned int*)&sample)&0x7f800000)==0) sample=0.0f

inline void process_comb(int index, float input, float* outputL, float* outputR) {
  float outL, outR;

  outL = l_comb_buffers[index][comb_buf_idx_l[index]];
  outR = r_comb_buffers[index][comb_buf_idx_r[index]];
  undenormalise(outL);
  undenormalise(outR);

  comb_filter_store_l[index] = (outL * (1-comb_damp_l[index])) + (comb_filter_store_l[index] * comb_damp_l[index]);
  comb_filter_store_r[index] = (outR * (1-comb_damp_r[index])) + (comb_filter_store_r[index] * comb_damp_r[index]);
  undenormalise(comb_filter_store_l[index]);
  undenormalise(comb_filter_store_r[index]);

  l_comb_buffers[index][comb_buf_idx_l[index]] = input + (comb_filter_store_l[index] * comb_feedback_l[index]);
  r_comb_buffers[index][comb_buf_idx_r[index]] = input + (comb_filter_store_r[index] * comb_feedback_r[index]);

  if (++comb_buf_idx_l[index]>=L_COMB_BUFFER_LENGTHS[index]) comb_buf_idx_l[index] = 0;
  if (++comb_buf_idx_r[index]>=R_COMB_BUFFER_LENGTHS[index]) comb_buf_idx_r[index] = 0;

  *outputL += outL;
  *outputR += outR;
} 

inline void process_allpass(int index, float input, float* outputL, float* outputR) {
  float outL, outR;
  float bufOutL, bufOutR;

  bufOutL = l_allpass_buffers[index][allpass_buf_idx_l[index]];
  bufOutR = r_allpass_buffers[index][allpass_buf_idx_r[index]];
  undenormalise(bufOutL);
  undenormalise(bufOutR);

  outL = -input + bufOutL;
  outR = -input + bufOutR;
  l_allpass_buffers[index][allpass_buf_idx_l[index]] = input + (bufOutL*allpass_feedback_l[index]);
  r_allpass_buffers[index][allpass_buf_idx_r[index]] = input + (bufOutR*allpass_feedback_r[index]);
  
  if (++allpass_buf_idx_l[index]>=L_ALLPASS_BUFFER_LENGTHS[index]) allpass_buf_idx_l[index] = 0;
  if (++allpass_buf_idx_r[index]>=R_ALLPASS_BUFFER_LENGTHS[index]) allpass_buf_idx_r[index] = 0;

  *outputL = outL;
  *outputR = outR;
} 

void compute_mix(float *input_l, float *input_r, float *output_l, float *output_r, long num_samples) {
  float outL, outR, input;
  
  while (num_samples-- > 0) {
    outL = outR = 0;
    input = (*input_l +*input_r) * gain;

    // accumulate comb filters in parallel
    for (int i = 0; i < NUM_COMBS; i++) {
      process_comb(i, input, &outL, &outR);
    }

    // Feed through allpasses in series
    for (int i = 0; i < NUM_ALLPASSES; i++) {
      process_allpass(i, input, &outL, &outR);
    }

    // Mix output
    *output_l += outL*wet1 + outR*wet2 + *input_l*dry;
    *output_r += outR*wet1 + outL*wet2 + *input_r*dry;
  }
}

void update_compute_internal() {
  int i;

  wet1 = wet*(width/2 + 0.5f);
  wet2 = wet*((1-width)/2);

  if (mode >= FREEZE_MODE) {
    roomsize1 = 1;
    damp1 = 0;
    gain = MUTED;
  } else {
    roomsize1 = roomsize;
    damp1 = damp;
    gain = FIXED_GAIN;
  }

  for (int i = 0; i < NUM_COMBS; i++) {
    comb_feedback_l[i] = roomsize1;
    comb_feedback_r[i] = roomsize1;
  }

  for (int i = 0; i < NUM_COMBS; i++) {
    comb_damp_l[i] = damp1;
    comb_damp_r[i] = damp1;
  }
}

void compute(int16_t* inputBufferL, int16_t* inputBufferR) {
  
}

//------ MAIN ------//

void loop() {
  //------ GET INPUT ------//
  // Wait for dma to finish
  dma_channel_wait_for_finish_blocking(dma_chan);
  
  // Stop and clean fifo
  adc_run(false);
  adc_fifo_drain();

  // Copy samples into buffer
  for (int i = 0; i < SAMPLES * 2; i++) {
    if (i % 2 == 0) {
      streamBufferL[i] = sampleBuffer[i]/4 - 512 + 49; // scale to working range: -512 to 512
    } else {
      streamBufferR[i] =  sampleBuffer[i]/4 - 512 + 49; // Scale to working range: -512 to 512.
    }
    
  }

  // Capture controls
  read_controls();

  // Restart capture
  dma_channel_configure(
    dma_chan,
    &config, 
    (uint16_t *)sampleBuffer,
    &adc_hw->fifo, 
    SAMPLES, 
    true
  );
  adc_run(true);

  // Compute
  compute(streamBufferL, streamBufferR);

  //------ OUTPUT ------//
  index_l = 0;
  index_r = 0;
}

int main() {
  init_adc_dma();
  init_controls();
  init_pwm();
  init_compute();

  while (1) {
    loop();
  }
}

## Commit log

2026-06-04 schematic :)
    [rev.kicad_pcb, rev.kicad_sch]
2026-06-06 pcb + panel
    [Panel.step, board.step, bom.ods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]
2026-06-06 panel art + blender
    [render.blend]
2026-08-07 finish zine
    [bom.csv, bom.ods, render.blend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]
2026-10-02 Add pcb screenshots
